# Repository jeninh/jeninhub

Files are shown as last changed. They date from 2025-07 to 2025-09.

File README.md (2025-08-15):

# jeninhub
A USB hub with 2 USB-A and 2 USB-C slots. Plugs into your laptop's USB-C slot.  


    
Made by @jeninh   

Contains:
- USB-C input
- 2 USB-C Ports
- 2 USB-A Ports
- Crystal + SL2.1A for MAXIMUM EFFICIENCY
- Mounted via mounting holes (2.2mm)
- 3d Printed Case

# Information :D
I made this because I just got a new laptop (yaaaay!!) and I wanted more ports. I also have a setup that connects my laptop to a wireless mouse, mic, monitor, etc when it's on my desk and I wanted to plug them all in at once!  
This hub has 2 USB-C ports and 1 USB-A ports

# PCB!!! THIS TOOK ME SO LONG 😭


This is the schematic! See that i also added a crystal connected to the SL2.1A :D so yeah

Front:


Back:


3d Preview after assembly:




Done in Kicad (the goat)... so yeah

# Case
DONE IN FUSION 360... OH MY DAYS THIS TOOK SO LONG





Difficulties I had with the case:
- LINING UP THE HOLES.... UGH MY MEASUREMENT SKILLS ARE DISGUSTING
- Sizing the height... I had to adjust this multiple times, especially after adding and switching the crystal
- Using fusion360 😭this is like my 2nd time

## BOM

| Name | Qty | Price (USD) | Link |
|---|-----|---|---|
| PCBA | 2 | NA | Out of Pocket |
| PCB | 5 | NA | Out of Pocket |
| USB-C to USB-C cable | 1 | NA | Out of Pocket |
| M2 x 6mm Screws | 4 | NA | Self Sourced |
| M2 Nuts | 4 | NA | Self Sourced |
| Top Case | 1 | NA | Self Printed |
| Bottom Case | 1 | NA | Self Printed |
*after taxes and conversion from CAD to USD. this is the cheapest USB-C product I can find that can come in time
    
Now... you may be wondering... why am I getting all these out of pocket?    
Well... I need to finish my project by August 7 which is about 9 days from when I am writing this and I defenitely won't get expedited shipping for free... so I might as well pay for my PCB and PCBA out of pocket so I get it on time!    
For the rest of the items... I am 3d printing the case myself and I have screws and nuts :)

## Notes
I like trains     
Rudy and Valen are goated for helping me with this      
Please accept me 😭 I am literally doing all of this out of pocket except for US$5 😭

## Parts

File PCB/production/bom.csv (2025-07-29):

Designator | Footprint | Quantity | Value | LCSC Part #
C1, C2, C3, C4, C5, C6, C7 | 0805 | 7 | 10 µF | C89827
J1, J2, J5 | USB_C_Receptacle_G-Switch_GT-USB-7010ASV | 3 | USB_C_Receptacle_USB2.0_16P | C2988369
J3, J4 | USB_A_Receptacle_GCT_USB1046 | 2 | USB_A | C5815145
R1, R2, R3, R4, R5, R6 | 0603 | 6 | 5.1 kΩ | C105580
U1 | SO16 | 1 | SL2.1A
Y1 | Crystal_SMD_3225-4Pin_3.2x2.5mm | 1 | 8 MHz Crystal | C518154

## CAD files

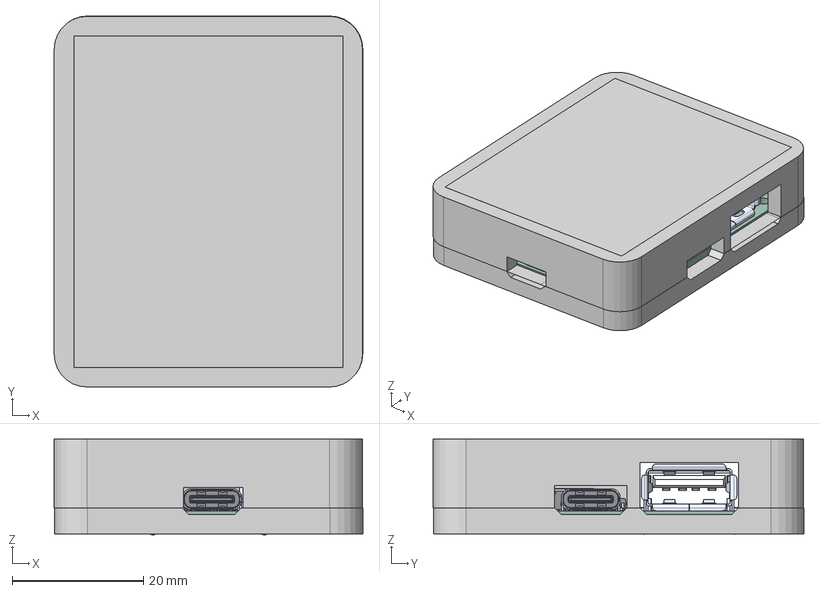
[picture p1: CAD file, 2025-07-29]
CAD/assembled.step
47.1 x 56.6 x 14.6 mm
R_0603_1608Metric x 6
C_0805_2012Metric x 7
TYPE-C-31-M-12 x 3
USB-A1HSW6 shell x 2
test x 2
SL2.1A--3DModel-STEP-269445
Crystal_SMD_3225-4Pin_3.2x2.5mm
jenin usb hub_PCB

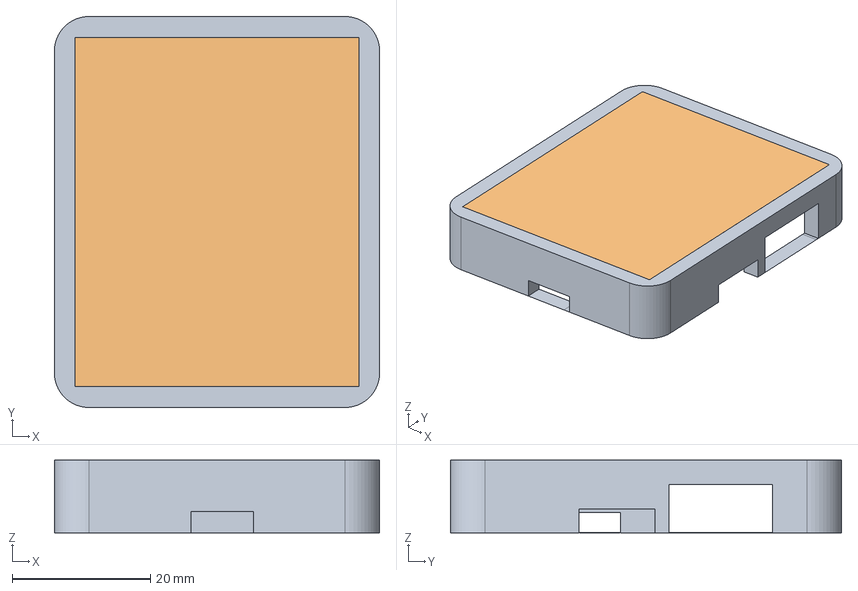
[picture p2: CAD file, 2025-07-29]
CAD/lid.step
47.0 x 56.5 x 10.5 mm

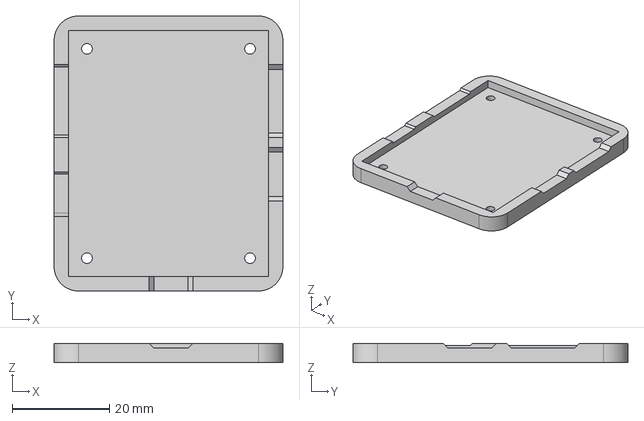
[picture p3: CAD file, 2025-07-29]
production/base.step
47.0 x 56.5 x 4.00 mm

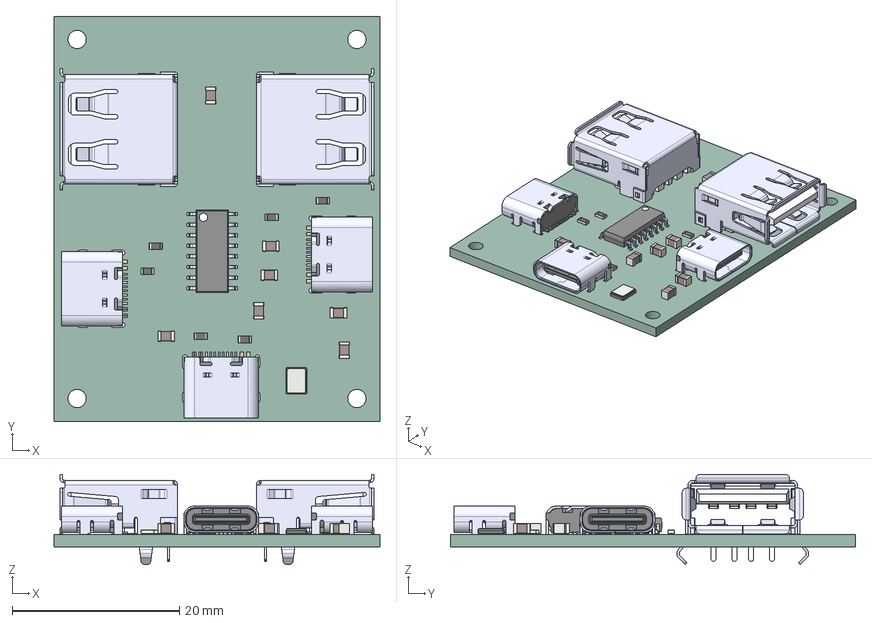
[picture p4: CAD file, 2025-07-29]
CAD/PCB.step
39.0 x 48.5 x 10.8 mm
R_0603_1608Metric x 6
C_0805_2012Metric x 7
TYPE-C-31-M-12 x 3
USB-A1HSW6 shell x 2
test x 2
SL2.1A--3DModel-STEP-269445
Crystal_SMD_3225-4Pin_3.2x2.5mm
jenin usb hub_PCB

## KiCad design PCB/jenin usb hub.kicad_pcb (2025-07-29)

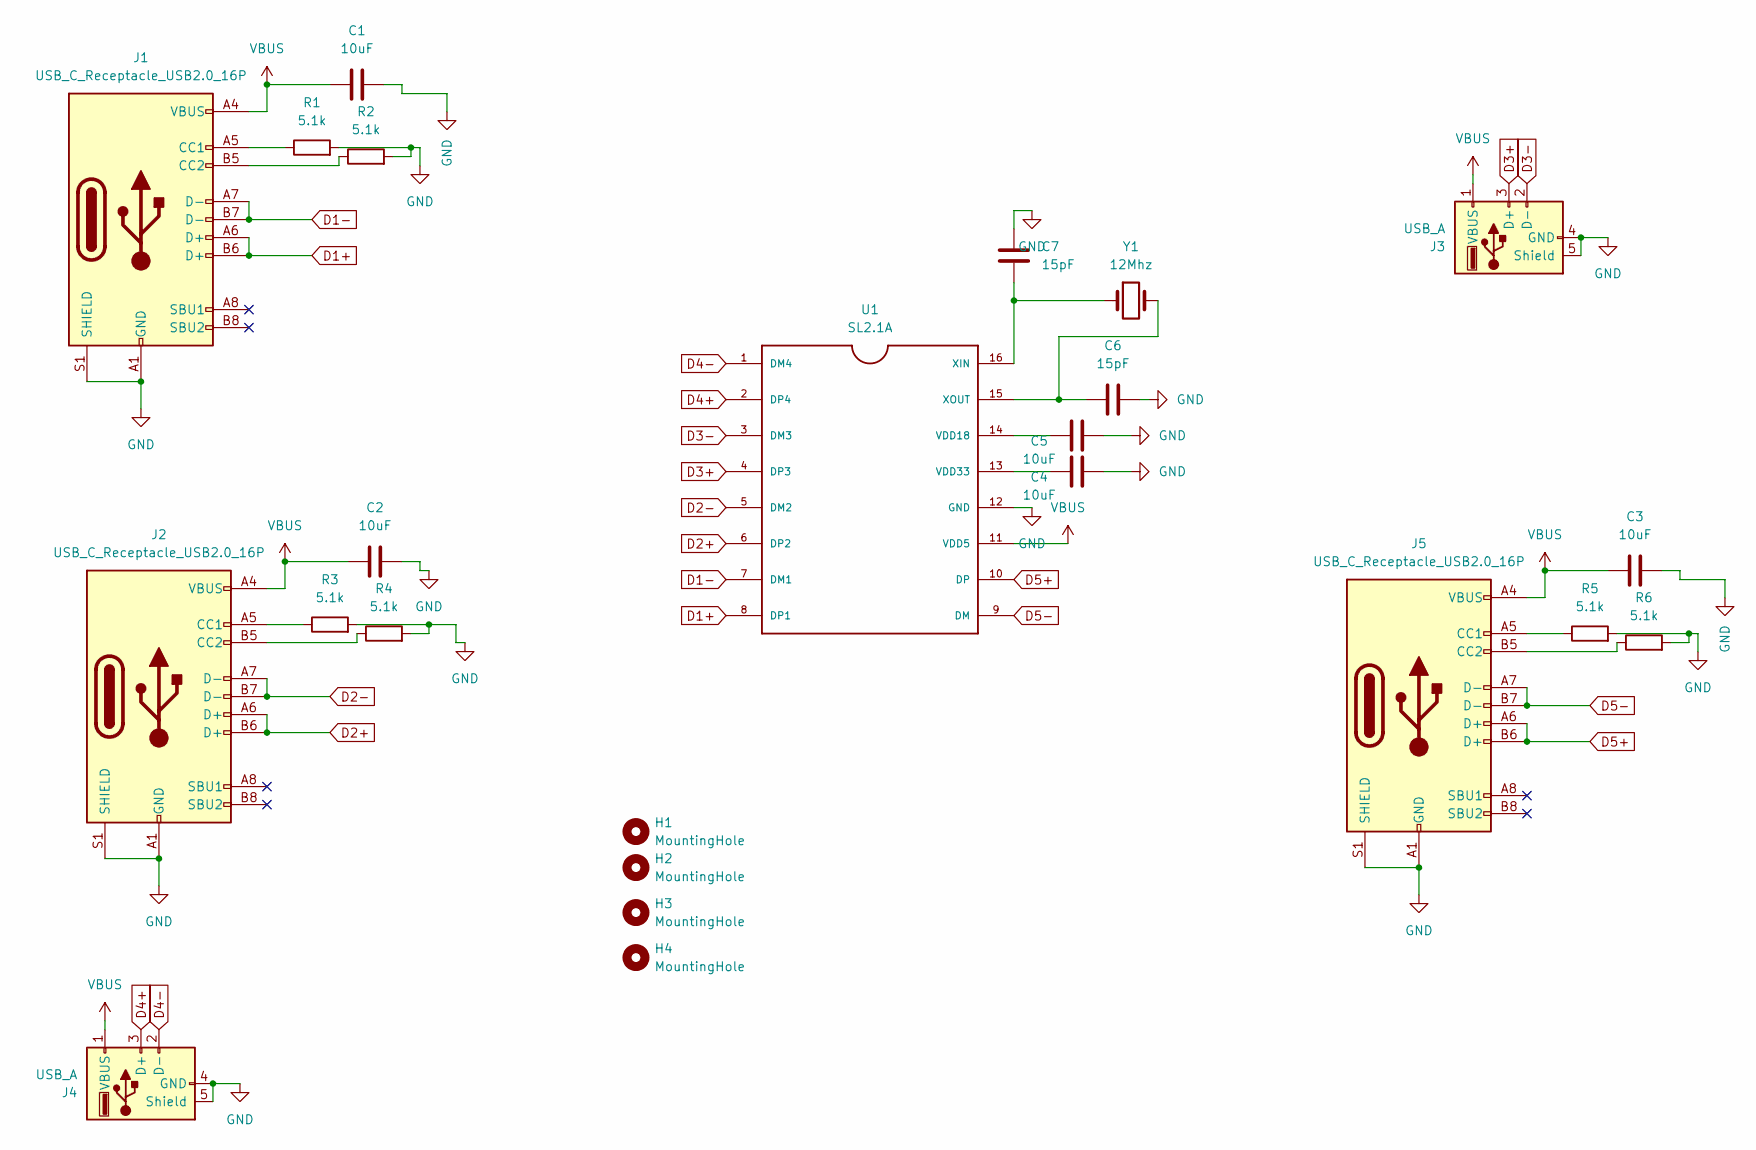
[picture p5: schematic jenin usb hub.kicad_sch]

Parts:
C1, C2, C3, C4, C5: 10uF; C_0805_2012Metric
C6, C7: 15pF; C_0805_2012Metric
H1, H2, H3, H4: MountingHole; MountingHole_2.2mm_M2
J1, J2, J5: USB_C_Receptacle_USB2.0_16P; USB_C_Receptacle_G-Switch_GT-USB-7010ASV
J3, J4: USB_A; USB_A_Receptacle_GCT_USB1046
R1, R2, R3, R4, R5, R6: 5.1k; R_0603_1608Metric
U1: SL2.1A; SO16
Y1: 12Mhz; Crystal_SMD_3225-4Pin_3.2x2.5mm

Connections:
D1+: J1.A6 (D+), J1.B6 (D+), U1.8 (DP1)
D1-: J1.A7 (D-), J1.B7 (D-), U1.7 (DM1)
D2+: J2.A6 (D+), J2.B6 (D+), U1.6 (DP2)
D2-: J2.A7 (D-), J2.B7 (D-), U1.5 (DM2)
D3+: J3.3 (D+), U1.4 (DP3)
D3-: J3.2 (D-), U1.3 (DM3)
D4+: J4.3 (D+), U1.2 (DP4)
D4-: J4.2 (D-), U1.1 (DM4)
D5+: J5.A6 (D+), J5.B6 (D+), U1.10 (DP)
D5-: J5.A7 (D-), J5.B7 (D-), U1.9 (DM)
GND: C1.2, C2.2, C3.2, C4.2, C5.2, C6.1, C7.1, J1.A1 (GND), J1.A12 (GND), J1.B1 (GND), J1.B12 (GND), J1.S1 (SHIELD), J2.A1 (GND), J2.A12 (GND), J2.B1 (GND), J2.B12 (GND), J2.S1 (SHIELD), J3.4 (GND), J3.5 (Shield), J4.4 (GND), J4.5 (Shield), J5.A1 (GND), J5.A12 (GND), J5.B1 (GND), J5.B12 (GND), J5.S1 (SHIELD), R1.2, R2.2, R3.2, R4.2, R5.2, R6.2, U1.12 (GND)
unnamed: J1.A5 (CC1), R1.1
unnamed: J1.B5 (CC2), R2.1
unnamed: J2.A5 (CC1), R3.1
unnamed: J2.B5 (CC2), R4.1
unnamed: J5.A5 (CC1), R5.1
unnamed: J5.B5 (CC2), R6.1
unnamed: C5.1, U1.14 (VDD18)
unnamed: C4.1, U1.13 (VDD33)
unnamed: C7.2, U1.16 (XIN), Y1.1
unnamed: C6.2, U1.15 (XOUT), Y1.2
VBUS: C1.1, C2.1, C3.1, J1.A4 (VBUS), J1.A9 (VBUS), J1.B4 (VBUS), J1.B9 (VBUS), J2.A4 (VBUS), J2.A9 (VBUS), J2.B4 (VBUS), J2.B9 (VBUS), J3.1 (VBUS), J4.1 (VBUS), J5.A4 (VBUS), J5.A9 (VBUS), J5.B4 (VBUS), J5.B9 (VBUS), U1.11 (VDD5)

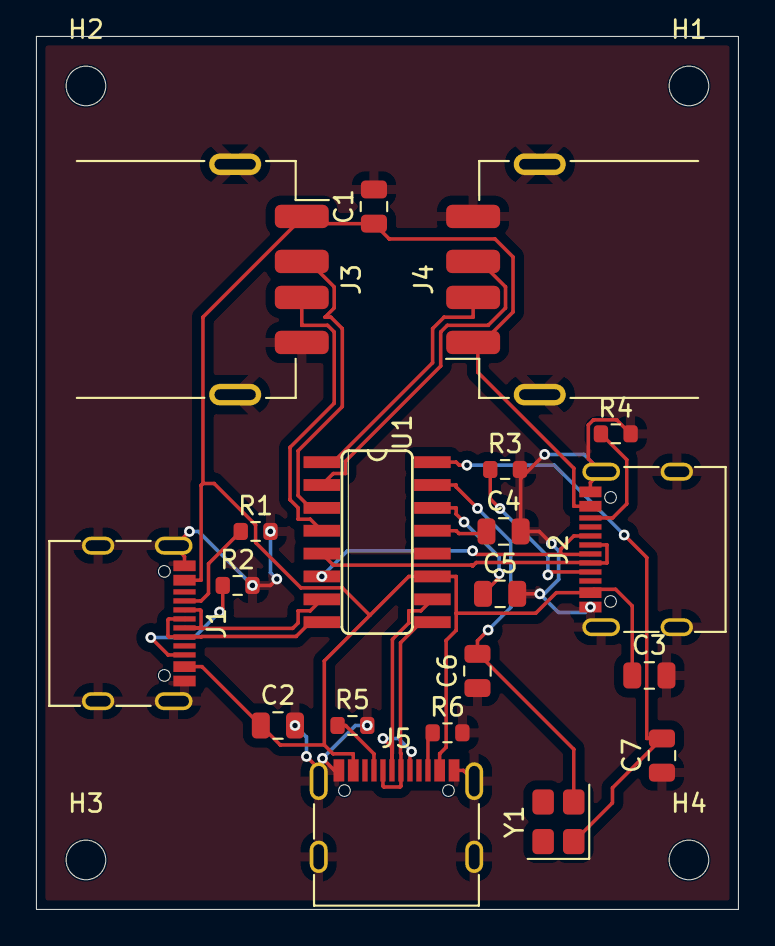
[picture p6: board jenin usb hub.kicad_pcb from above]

Board: 2 copper layers, 39.0 x 48.5 mm, 24 parts (0 on the bottom side), 22 nets.

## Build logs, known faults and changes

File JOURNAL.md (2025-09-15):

---
title: "Jeninhub"
author: "jenin"
description: "A USB hub with 2 USB-A slots and 2 USB-C slots!"
created_at: "2025-07-23"
---
# TOTAL TIME SPENT: 17 HOURS AND 45 MINUTES (how did it take this long 😭)

## July 23rd, 2025 - Started the project!
I forgot to journal so here I am on the 25th rejournaling! Today I came up with my idea, and started the CAD! I'm really new to this so I learned how to use USB-A ports in KiCad!   


Credit to some people in the KiCad EDA discord for helping me learn some basic schematic stuff like putting VBUS facing up and GND facing down!!  
**Time spent today: ~1.5hrs**
## July 24th, 2025
Today I learned how to use USB-C ports, and tried to use a MicroSD card reader! that failed so we're scrapping the microsd card... now just 2 usba and 2 usbc :(  


**Time spent today: 2.5hrs**

## July 25th, 2025
Today I found out how to use and wire a SL2.1A piece to control my USB hub! I also finished the schematic (image below) and started doing the placement for the PCB! Oh and I also added some mounting holes...    


I also did a lot of the wiring... But it ended up not working and I had to redo it :noooo:
**Time spent today: 2.5hrs**

## July 26th, 2025
I did a lot of the wiring.... and then realized that I was using the wrong footprint :noooo:, oh and I DID SOME CAD!!! I REDID THE BASE 4 TIMES CUZ I DIDNT KNOW HOW TO USE MOUNTING HOLES 😭
**Time spent today: 1h30m**

## July 27th, 2025
Didn't do much today, went to church, just did some CADding!

(this is the complete render, screenshottted on the 28th but on the 27th i only did the base)
**Time spent today: 1hr**
## July 28th, 2025
Boy oh boy... Today I grinded..    
Today I:
1. Did all the routing... twice... then learned how to diff pair and ground pour so my thing does explode 😭
2. DID ALL THE CAD 💪 HAD TO FIX MY FREAKING MOUTNING HOLES LIKE 17 TIMES BUT ITS OK :pf:
3. GOT THE BOM (will upload soon)

Update from evening:
APPARENTLY I NEED A CRYSTAL SO MY PCB DOESNT EXPLODE 😭 so i did that... and had to reroute again.... i actually used a ground pour and differential pair this time!! are you proud of me cyao    


**Time spent today: 6hrs**

## July 29th, 2025
I wake up, think I'm ready to ship because i finished the CAD and all, and then i see that that little crystall IS TALL.
     
so i redid the cad in about 45mins just making it taller because i am disgusting with fusion
   
here's 2 photos of the cad, one transparent one not



I'm now going to ship this and add the time it takes to do that to my journal.    

Update: I USED THE WRONG CRYSTAL 😭 I had to redo the cad and the PCB wiring and footprint and adjust my BOM.



This is the new case with new PCB ^^     

AND WE'RE DONE!!! HAD TO REDO ALL THE FILES IN THE GITHUB AND ALL THAT BUT I'M DONE!
**Time spent today: 2hrs 45mins**

## Assembly
Had some PCB issues, the crystal was 8mhz but i cut the trace and made it ran on the IC so we good.
**Time spent: 2 hours**


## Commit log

2025-07-29 Update and rename hi.txt to bom.csv
    [bom.csv]
2025-09-15 Add assembly section and PCB issue notes
    Documented assembly work and PCB issues encountered.
